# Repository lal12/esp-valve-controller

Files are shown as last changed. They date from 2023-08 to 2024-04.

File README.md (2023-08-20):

# ESP32 heating valve controller

This projects is about an ESP32 based heating valve controller using Homematic IP actors to control heating valves,
usually for floorboard heating.

## ESPHOME

Included in this repository are esphome configs for controlling the motors.
Include them with the following lines in your esphome config yml:

```
packages:
  valve_controller_2_0:
    url: https://github.com/lal12/esp-valve-controller
    ref: master
    file: esphome/v2.0.yml
    refresh: 1d # optional
    vars:
      LED_INTERNAL: false
  valve_controller_1_0:
    url: https://github.com/lal12/esp-valve-controller
    ref: master
    file: esphome/v1.0.yml
    refresh: 1d # optional
```

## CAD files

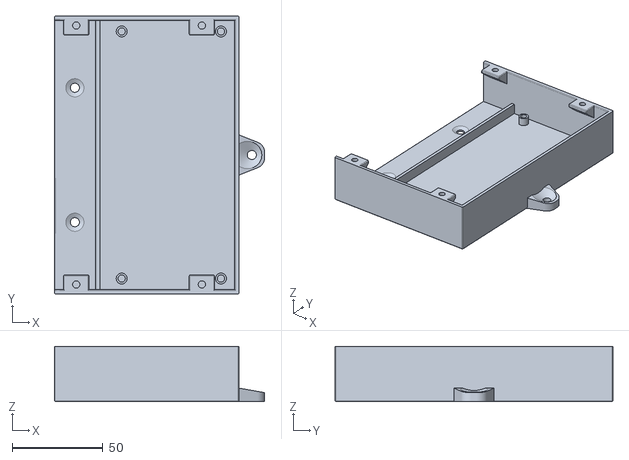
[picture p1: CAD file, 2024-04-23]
case/v2/valve_controller_case.stl
115.6 x 152.9 x 30.5

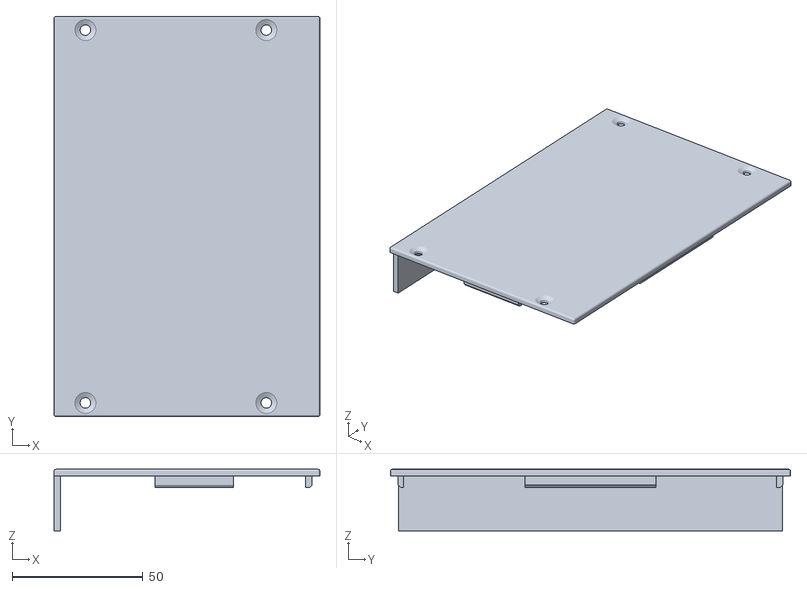
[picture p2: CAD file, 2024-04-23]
case/v2/valve_controller_case_cover.stl
101.6 x 152.9 x 23.5

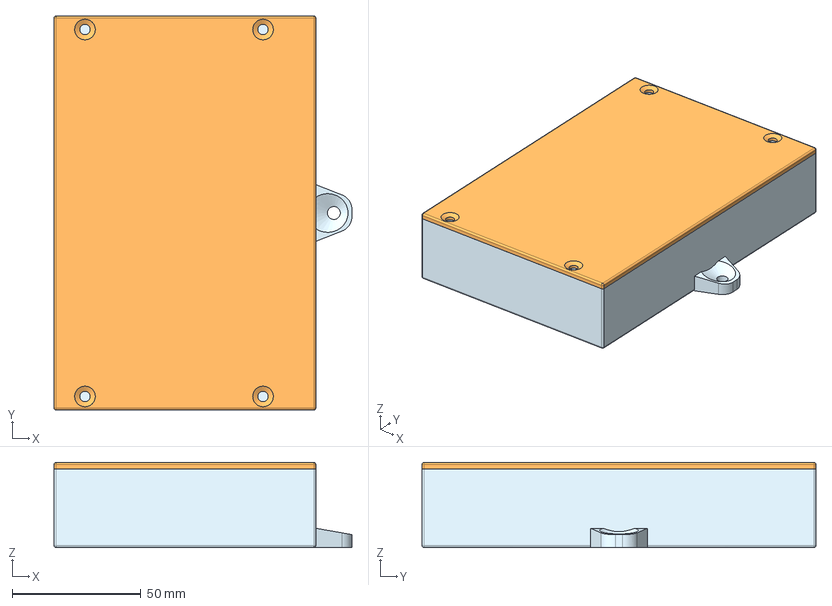
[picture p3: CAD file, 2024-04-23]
case/v2/heating_valve_controller_case.step
115.6 x 152.9 x 33.0 mm

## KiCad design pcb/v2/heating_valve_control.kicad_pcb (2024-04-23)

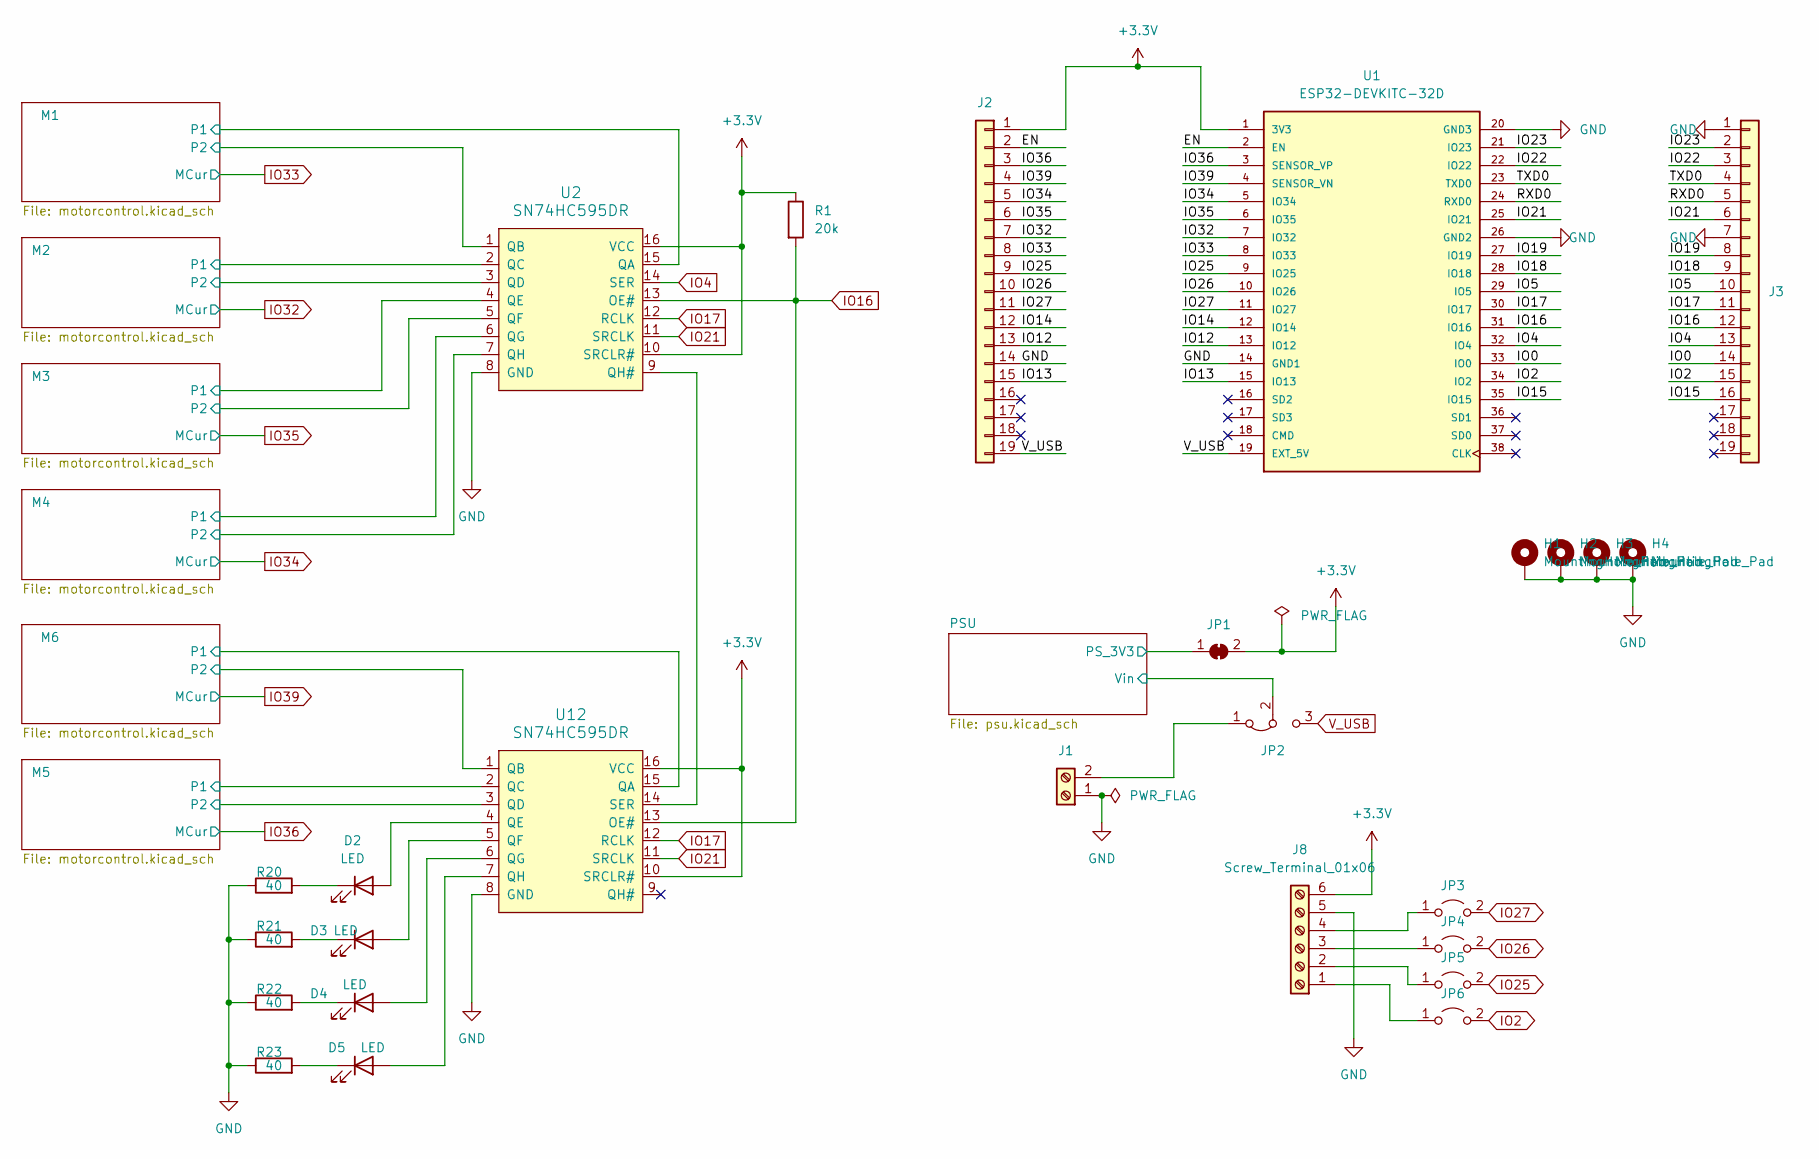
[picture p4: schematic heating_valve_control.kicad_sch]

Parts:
D2, D3, D4, D5: LED; LED0603-R-RD_WHITE
H1, H2, H3, H4: MountingHole_Pad; MountingHole_3.2mm_M3_Pad_TopBottom
J1: Screw_Terminal_01x02; TerminalBlock_bornier-2_P5.08mm
J2, J3: Conn_01x19; PinHeader_1x19_P2.54mm_Vertical
J8: Screw_Terminal_01x06; TerminalBlock_RND_205-00236_1x06_P5.08mm_Horizontal
JP1: SolderJumper_2_Bridged; SolderJumper-2_P1.3mm_Bridged_RoundedPad1.0x1.5mm
JP2: Jumper_3_Bridged12; PinHeader_1x03_P2.54mm_Vertical
JP3, JP4, JP5, JP6: Jumper_2_Open; TestPoint_2Pads_Pitch2.54mm_Drill0.8mm
R1: 20k; R_0402_1005Metric_Pad0.72x0.64mm_HandSolder
R20, R21, R22, R23: 40; R_0402_1005Metric_Pad0.72x0.64mm_HandSolder
U1: ESP32-DEVKITC-32D; MODULE_ESP32-DEVKITC-32D; PARTREV 4
U2, U12: SN74HC595DR; SOIC-16_L9.9-W3.9-P1.27-LS6.0-BL; LCSC Part C10092

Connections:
+3.3V: J2.1, J8.6, JP1.2 (B), R1.1, U1.1 (3V3), U2.10 (SRCLR#), U2.16 (VCC), U12.10 (SRCLR#), U12.16 (VCC); also elsewhere on the board
/EN: J2.2, U1.2 (EN)
/IO0: J3.14, U1.33 (IO0)
/IO5: J3.10, U1.29 (IO5)
/IO12: J2.13, U1.13 (IO12)
/IO13: J2.15, U1.15 (IO13)
/IO14: J2.12, U1.12 (IO14)
/IO15: J3.16, U1.35 (IO15)
/IO18: J3.9, U1.28 (IO18)
/IO19: J3.8, U1.27 (IO19)
/IO22: J3.3, U1.22 (IO22)
/IO23: J3.2, U1.21 (IO23)
/M1/P1: U2.15 (QA); also elsewhere on the board
/M1/P2: U2.1 (QB); also elsewhere on the board
/M2/P1: U2.2 (QC); also elsewhere on the board
/M2/P2: U2.3 (QD); also elsewhere on the board
/M3/P1: U2.4 (QE); also elsewhere on the board
/M3/P2: U2.5 (QF); also elsewhere on the board
/M4/P1: U2.6 (QG); also elsewhere on the board
/M4/P2: U2.7 (QH); also elsewhere on the board
/M5/P1: U12.2 (QC); also elsewhere on the board
/M5/P2: U12.3 (QD); also elsewhere on the board
/M6/P1: U12.15 (QA); also elsewhere on the board
/M6/P2: U12.1 (QB); also elsewhere on the board
/PSU/PS_3V3: JP1.1 (A); also elsewhere on the board
/PSU/Vin: JP2.2 (C); also elsewhere on the board
/RXD0: J3.5, U1.24 (RXD0)
/TXD0: J3.4, U1.23 (TXD0)
GND: H1.1, H2.1, H3.1, H4.1, J1.1, J2.14, J3.1, J3.7, J8.5, R20.1, R21.1, R22.1, R23.1, U1.14 (GND1), U1.20 (GND3), U1.26 (GND2), U2.8 (GND), U12.8 (GND); also elsewhere on the board
IO2: J3.15, JP6.2 (B), U1.34 (IO2)
IO4: J3.13, U1.32 (IO4), U2.14 (SER)
IO16: J3.12, R1.2, U1.31 (IO16), U2.13 (OE#), U12.13 (OE#)
IO17: J3.11, U1.30 (IO17), U2.12 (RCLK), U12.12 (RCLK)
IO21: J3.6, U1.25 (IO21), U2.11 (SRCLK), U12.11 (SRCLK)
IO25: J2.9, JP5.2 (B), U1.9 (IO25)
IO26: J2.10, JP4.2 (B), U1.10 (IO26)
IO27: J2.11, JP3.2 (B), U1.11 (IO27)
IO32: J2.7, U1.7 (IO32); also elsewhere on the board
IO33: J2.8, U1.8 (IO33); also elsewhere on the board
IO34: J2.5, U1.5 (IO34); also elsewhere on the board
IO35: J2.6, U1.6 (IO35); also elsewhere on the board
IO36: J2.3, U1.3 (SENSOR_VP); also elsewhere on the board
IO39: J2.4, U1.4 (SENSOR_VN); also elsewhere on the board
unnamed: D2.2 (A), U12.4 (QE)
unnamed: D2.1 (K), R20.2
unnamed: D3.2 (A), U12.5 (QF)
unnamed: D3.1 (K), R21.2
unnamed: D4.2 (A), U12.6 (QG)
unnamed: D4.1 (K), R22.2
unnamed: D5.2 (A), U12.7 (QH)
unnamed: D5.1 (K), R23.2
unnamed: J1.2, JP2.1 (A)
unnamed: J8.1, JP6.1 (A)
unnamed: J8.2, JP5.1 (A)
unnamed: J8.3, JP4.1 (A)
unnamed: J8.4, JP3.1 (A)
unnamed: U2.9 (QH#), U12.14 (SER)
V_USB: J2.19, JP2.3 (B), U1.19 (EXT_5V)

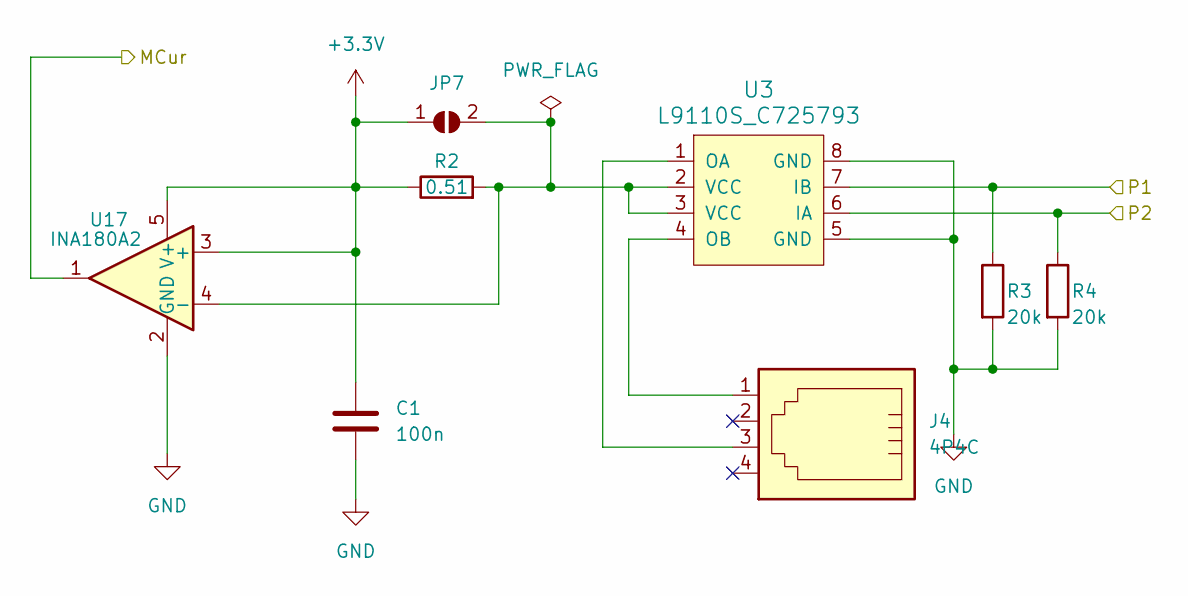
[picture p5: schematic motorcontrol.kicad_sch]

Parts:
C1: 100n; C_0603_1608Metric_Pad1.08x0.95mm_HandSolder
J4: 4P4C; RJ11-TH_616-PCB-4P4C-90
JP7: SolderJumper_2_Open; SolderJumper-2_P1.3mm_Open_RoundedPad1.0x1.5mm
R2: 0.51; R_1206_3216Metric_Pad1.30x1.75mm_HandSolder
R3, R4: 20k; R_0402_1005Metric_Pad0.72x0.64mm_HandSolder
U3: L9110S_C725793; SOP-8_L6.1-W3.9-P1.27-LS6.0-BL-1; LCSC Part C725793
U17: INA180A2; SOT-23-5

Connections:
+3.3V: C1.1, JP7.1 (A), R2.1, U17.3 (+), U17.5 (V+); also elsewhere on the board
/M1/P1: R3.1, U3.7 (IB); also elsewhere on the board
/M1/P2: R4.1, U3.6 (IA); also elsewhere on the board
GND: C1.2, R3.2, R4.2, U3.5 (GND), U3.8 (GND), U17.2 (GND); also elsewhere on the board
IO33: U17.1; also elsewhere on the board
unnamed: JP7.2 (B), R2.2, U3.2 (VCC), U3.3 (VCC), U17.4 (-)
unnamed: J4.3, U3.1 (OA)
unnamed: J4.1, U3.4 (OB)

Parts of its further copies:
C2, C3, C4, C7, C8: 100n; C_0603_1608Metric_Pad1.08x0.95mm_HandSolder
J5, J6, J7, J9, J10: 4P4C; RJ11-TH_616-PCB-4P4C-90
JP8, JP9, JP10, JP11, JP12: SolderJumper_2_Open; SolderJumper-2_P1.3mm_Open_RoundedPad1.0x1.5mm
R5, R8, R11, R14, R17: 0.51; R_1206_3216Metric_Pad1.30x1.75mm_HandSolder
R6, R7, R9, R10, R12, R13, R15, R16, R18, R19: 20k; R_0402_1005Metric_Pad0.72x0.64mm_HandSolder
U5, U7, U9, U13, U15: L9110S_C725793; SOP-8_L6.1-W3.9-P1.27-LS6.0-BL-1; LCSC Part C725793
U18, U19, U20, U21, U22: INA180A2; SOT-23-5

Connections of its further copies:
+3.3V: C2.1, C3.1, C4.1, C7.1, C8.1, JP8.1 (A), JP9.1 (A), JP10.1 (A), JP11.1 (A), JP12.1 (A), R5.1, R8.1, R11.1, R14.1, R17.1, U18.3 (+), U18.5 (V+), U19.3 (+), U19.5 (V+), U20.3 (+), U20.5 (V+), U21.3 (+), U21.5 (V+), U22.3 (+), U22.5 (V+); also elsewhere on the board
/M2/P1: R6.1, U5.7 (IB); also elsewhere on the board
/M2/P2: R7.1, U5.6 (IA); also elsewhere on the board
/M3/P1: R9.1, U7.7 (IB); also elsewhere on the board
/M3/P2: R10.1, U7.6 (IA); also elsewhere on the board
/M4/P1: R12.1, U9.7 (IB); also elsewhere on the board
/M4/P2: R13.1, U9.6 (IA); also elsewhere on the board
/M5/P1: R18.1, U15.7 (IB); also elsewhere on the board
/M5/P2: R19.1, U15.6 (IA); also elsewhere on the board
/M6/P1: R15.1, U13.7 (IB); also elsewhere on the board
/M6/P2: R16.1, U13.6 (IA); also elsewhere on the board
GND: C2.2, C3.2, C4.2, C7.2, C8.2, R6.2, R7.2, R9.2, R10.2, R12.2, R13.2, R15.2, R16.2, R18.2, R19.2, U5.5 (GND), U5.8 (GND), U7.5 (GND), U7.8 (GND), U9.5 (GND), U9.8 (GND), U13.5 (GND), U13.8 (GND), U15.5 (GND), U15.8 (GND), U18.2 (GND), U19.2 (GND), U20.2 (GND), U21.2 (GND), U22.2 (GND); also elsewhere on the board
IO32: U18.1; also elsewhere on the board
IO34: U20.1; also elsewhere on the board
IO35: U19.1; also elsewhere on the board
IO36: U22.1; also elsewhere on the board
IO39: U21.1; also elsewhere on the board
unnamed: JP8.2 (B), R5.2, U5.2 (VCC), U5.3 (VCC), U18.4 (-)
unnamed: JP9.2 (B), R8.2, U7.2 (VCC), U7.3 (VCC), U19.4 (-)
unnamed: JP10.2 (B), R11.2, U9.2 (VCC), U9.3 (VCC), U20.4 (-)
unnamed: JP11.2 (B), R14.2, U13.2 (VCC), U13.3 (VCC), U21.4 (-)
unnamed: JP12.2 (B), R17.2, U15.2 (VCC), U15.3 (VCC), U22.4 (-)
unnamed: J5.3, U5.1 (OA)
unnamed: J5.1, U5.4 (OB)
unnamed: J6.3, U7.1 (OA)
unnamed: J6.1, U7.4 (OB)
unnamed: J7.3, U9.1 (OA)
unnamed: J7.1, U9.4 (OB)
unnamed: J9.3, U13.1 (OA)
unnamed: J9.1, U13.4 (OB)
unnamed: J10.3, U15.1 (OA)
unnamed: J10.1, U15.4 (OB)

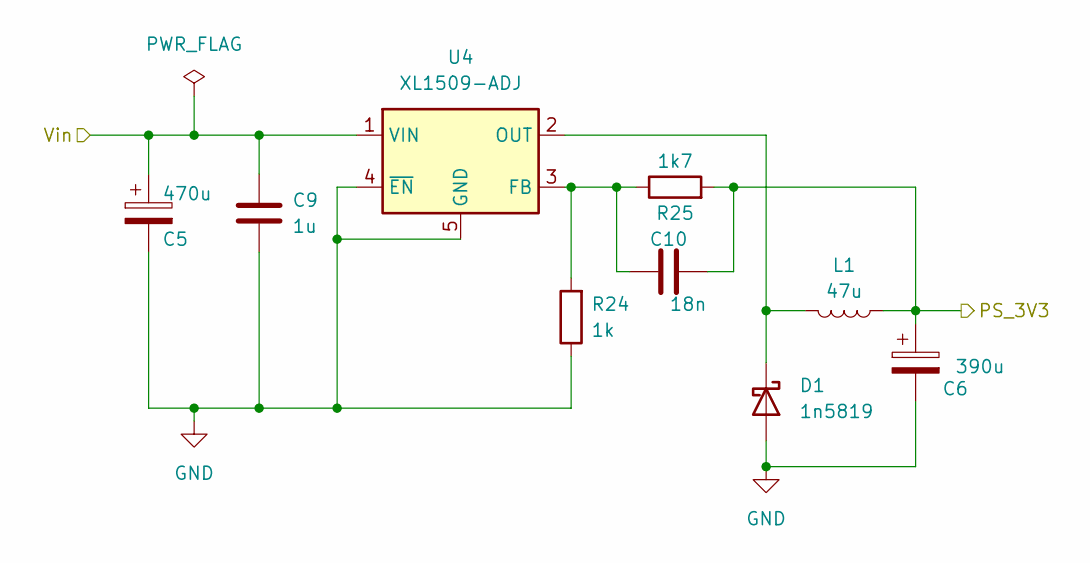
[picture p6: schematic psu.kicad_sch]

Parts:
C5: 470u; CAP-SMD_BD10.0-L10.3-W10.3-LS11.3-FD
C6: 390u; CAP-SMD_BD10.0-L10.3-W10.3-LS11.3-FD
C9: 1u; C_0603_1608Metric_Pad1.08x0.95mm_HandSolder
C10: 18n; C_0603_1608Metric_Pad1.08x0.95mm_HandSolder
D1: 1n5819; D_SOD-323_HandSoldering
L1: 47u; IND-SMD_L7.1-W6.6
R24: 1k; R_0402_1005Metric_Pad0.72x0.64mm_HandSolder
R25: 1k7; R_0402_1005Metric_Pad0.72x0.64mm_HandSolder
U4: XL1509-ADJ; SOIC-8_3.9x4.9mm_P1.27mm

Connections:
/PSU/PS_3V3: C6.1, C10.2, L1.1, R25.2; also elsewhere on the board
/PSU/Vin: C5.1, C9.1, U4.1 (VIN); also elsewhere on the board
GND: C5.2, C6.2, C9.2, D1.2 (A), R24.1, U4.4 (~EN), U4.5 (GND), U4.6 (GND), U4.7 (GND), U4.8 (GND); also elsewhere on the board
unnamed: D1.1 (K), L1.2, U4.2 (OUT)
unnamed: C10.1, R24.2, R25.1, U4.3 (FB)

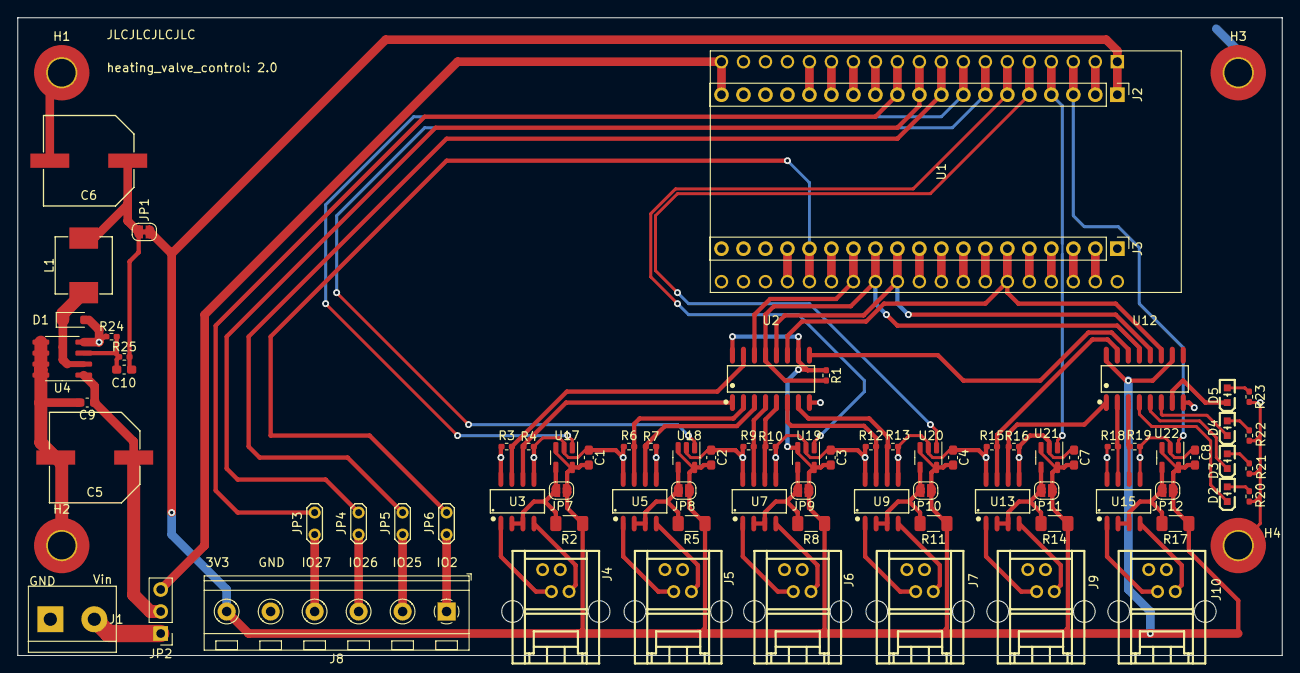
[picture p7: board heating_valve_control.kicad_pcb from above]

Board: 2 copper layers, 146.1 x 73.7 mm, 83 parts (0 on the bottom side), 78 nets.

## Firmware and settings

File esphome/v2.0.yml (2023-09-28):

substitutions:
  LED_INTERNAL: 'false'
  OPEN_DURATION: 40s
  CLOSE_DURATION: 50s
  CURRENT_THRESHOLD: '1.9'

sn74hc595:
  - id: 'sn74hc595_hub'
    data_pin: GPIO4
    clock_pin: GPIO21
    latch_pin: GPIO17
    oe_pin: GPIO16
    sr_count: 2

packages:
  m1: !include
    file: ./motor.yml
    vars:
      ID_PREFIX: m1
      NAME: "Motor 1"
      SHIFTREG_ID: sn74hc595_hub
      PIN_CLOSE_NO: 0
      PIN_OPEN_NO: 1
      PIN_ADC: GPIO33
      CURRENT_THRESHOLD: ${CURRENT_THRESHOLD}
      OPEN_DURATION: ${OPEN_DURATION}
      CLOSE_DURATION: ${CLOSE_DURATION}
  m2: !include
    file: ./motor.yml
    vars:
      ID_PREFIX: m2
      NAME: "Motor 2"
      SHIFTREG_ID: sn74hc595_hub
      PIN_CLOSE_NO: 2
      PIN_OPEN_NO: 3
      PIN_ADC: GPIO32
      CURRENT_THRESHOLD: ${CURRENT_THRESHOLD}
      OPEN_DURATION: ${OPEN_DURATION}
      CLOSE_DURATION: ${CLOSE_DURATION}
  m3: !include
    file: ./motor.yml
    vars:
      ID_PREFIX: m3
      NAME: "Motor 3"
      SHIFTREG_ID: sn74hc595_hub
      PIN_CLOSE_NO: 4
      PIN_OPEN_NO: 5
      PIN_ADC: GPIO35
      CURRENT_THRESHOLD: ${CURRENT_THRESHOLD}
      OPEN_DURATION: ${OPEN_DURATION}
      CLOSE_DURATION: ${CLOSE_DURATION}
  m4: !include
    file: ./motor.yml
    vars:
      ID_PREFIX: m4
      NAME: "Motor 4"
      SHIFTREG_ID: sn74hc595_hub
      PIN_CLOSE_NO: 6
      PIN_OPEN_NO: 7
      PIN_ADC: GPIO34
      CURRENT_THRESHOLD: ${CURRENT_THRESHOLD}
      OPEN_DURATION: ${OPEN_DURATION}
      CLOSE_DURATION: ${CLOSE_DURATION}
  m5: !include
    file: ./motor.yml
    vars:
      ID_PREFIX: m5
      NAME: "Motor 5"
      SHIFTREG_ID: sn74hc595_hub
      PIN_CLOSE_NO: 8
      PIN_OPEN_NO: 9
      PIN_ADC: GPIO39
      CURRENT_THRESHOLD: ${CURRENT_THRESHOLD}
      OPEN_DURATION: ${OPEN_DURATION}
      CLOSE_DURATION: ${CLOSE_DURATION}
  m6: !include
    file: ./motor.yml
    vars:
      ID_PREFIX: m6
      NAME: "Motor 6"
      SHIFTREG_ID: sn74hc595_hub
      PIN_CLOSE_NO: 10
      PIN_OPEN_NO: 11
      PIN_ADC: GPIO36
      CURRENT_THRESHOLD: ${CURRENT_THRESHOLD}
      OPEN_DURATION: ${OPEN_DURATION}
      CLOSE_DURATION: ${CLOSE_DURATION}

# Individual outputs
switch:
  - platform: gpio
    id: led1
    name: "LED1"
    pin:
      sn74hc595: sn74hc595_hub
      number: 12
      inverted: false
    internal: ${LED_INTERNAL}
  - platform: gpio
    id: led2
    name: "LED2"
    pin:
      sn74hc595: sn74hc595_hub
      number: 13
      inverted: false
    internal: ${LED_INTERNAL}
  - platform: gpio
    id: led3
    name: "LED3"
    pin:
      sn74hc595: sn74hc595_hub
      number: 14
      inverted: false
    internal: ${LED_INTERNAL}
  - platform: gpio
    id: led4
    name: "LED4"
    pin:
      sn74hc595: sn74hc595_hub
      number: 15
      inverted: false
    internal: ${LED_INTERNAL}

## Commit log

2023-08-20 v2.0: made LED internal configurable
2023-09-27 - made more variables configurable - removed accidental LED entries for v1
    [motor.yml]
2024-04-23 added case and pcb
    [heating_valve_control.kicad_pcb, heating_valve_control.kicad_sch, heating_valve_controller_case.step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]
2024-12-17 v1.0.yml make CURRENT_THRESHOLD substititutable and slightly increase default
2024-12-17 motor made internals hidden (internal: true)
    [motor.yml]
2024-12-17 increased current threshold
2026-10-12 Refactor CURRENT_THRESHOLD to multiple variables
2026-10-12 Add multiple current threshold variables for motors
2026-10-14 Add INTERNAL_CURRENT_SENSOR and update ADC configuration
    Added INTERNAL_CURRENT_SENSOR substitution and updated ADC sensor internal property.
2026-10-14 Update motor configuration with new parameters
    Added INRUSH_BLANKING_MS and STALL_CONFIRM variables to motor configurations.
2026-10-14 Enhance motor control with inrush and stall detection
    Added inrush current blanking and stall confirmation parameters. Updated binary sensor logic and cover actions to handle new parameters.
2026-10-14 Update current thresholds and inrush blanking time
2026-10-14 Add internal current sensor and related parameters
2026-10-14 Modify motor.yml for current sensor attenuation
    Updated current sensor configuration with attenuation settings and clarified comments.
2026-10-14 Fix formatting of STALL_CONFIRM in v1.0.yml
